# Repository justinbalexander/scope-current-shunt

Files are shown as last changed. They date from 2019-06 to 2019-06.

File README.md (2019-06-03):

# Current monitor

## Description

This project implements a simple current sensor to measure the current draw of
some low power sensor nodes. The devices can be hooked up to an oscilloscope
and the current draw recorded to get another window into the device operation
over time.

The batteries required are 3V CR123A batteries.

The DUT current draw range should be less than or equal to about 30mV.  The
intention is to watch the current draw using a Siglent SDS1202X-E with the
vertical axis set to 100 mV/div. The expected max Vo is 687.69mV which is
almost all of the screen size of 772mV to minimize quantization error in the
oscilloscope.

## Implementation

The design was described using Skidl and pcb designed using Kicad:

https://github.com/xesscorp/skidl

## Build Instructions

Skidl is required:

```bash
pip3 install skidl
```

To rebuild the netlist for importing into pcbnew:

```bash
./scope-current-shunt.py
```

Open the file scope-current-shunt.kicad_pcb in pcbnew to edit the pcb.

## Render

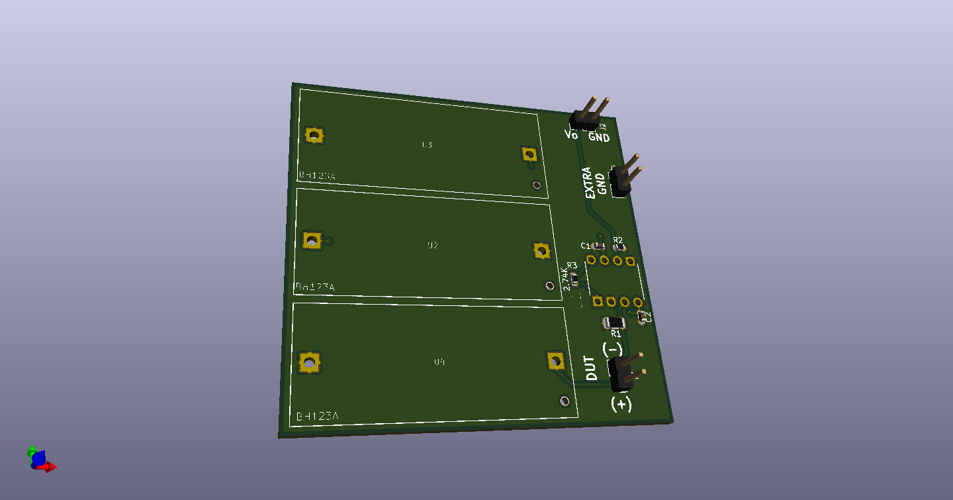
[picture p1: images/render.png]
render


## Attributions

Some symbols and footprints  came from www.snapeda.com. See the library folder for the required
license and attributions.

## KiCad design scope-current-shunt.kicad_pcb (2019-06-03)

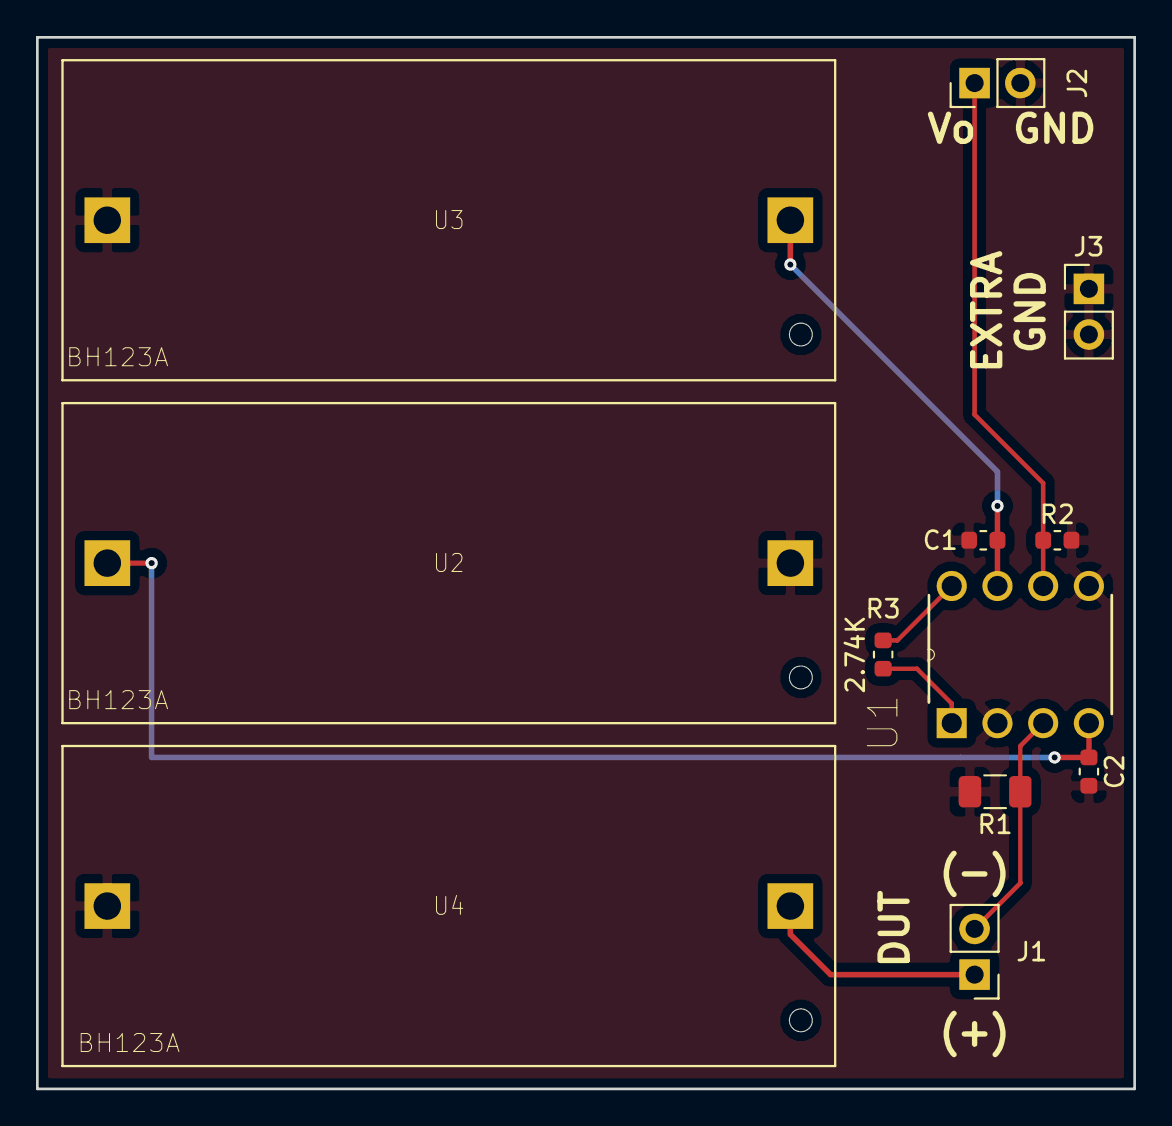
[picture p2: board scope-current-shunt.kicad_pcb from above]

Board: 2 copper layers, 61.0 x 58.4 mm, 12 parts (0 on the bottom side), 8 nets.

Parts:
C1, C2: 0.1uF; C_0603_1608Metric
J1: Screw_Terminal_01x02; PinHeader_1x02_P2.54mm_Vertical
J2, J3: Conn_01x02_Male; PinHeader_1x02_P2.54mm_Vertical
R1: 1; R_1206_3216Metric
R2: R2.5K; R_0603_1608Metric
R3: 2.74K; R_0603_1608Metric
U1: INA129P; DIP254P762X508-8
U2, U3, U4: BH123A

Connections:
GND: C1.2, C2.2, J2.2, J3.1, J3.2, R1.2, R2.2, U1.2, U1.5, U2.+, U3.-, U4.-
unnamed: R3.1, U1.8
unnamed: R3.2, U1.1
unnamed: J1.2, R1.1, U1.3
V+: C1.1, U1.7, U3.+
V-: C2.1, U1.4, U2.-
VDD: J1.1, U4.+
Vo: J2.1, R2.1, U1.6

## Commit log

2019-06-02 Add empty kicad project files
    [scope-current-shunt.kicad_pcb]
2019-06-02 Add INA129 symbol and footprint
2019-06-02 Add BH123A CR123 battery holder symbol and footprint
2019-06-02 Add skidl description of circuit
2019-06-03 First board layout
    [scope-current-shunt.kicad_pcb]
2019-06-03 Generate Gerbers
    [scope-current-shunt-B.Cu.gbr, scope-current-shunt-B.Mask.gbr, scope-current-shunt-B.SilkS.gbr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]
